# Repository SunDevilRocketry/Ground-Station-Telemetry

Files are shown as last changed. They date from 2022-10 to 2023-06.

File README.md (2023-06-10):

<h1>Ground Station Telemetry Unit</h1>

<p>Current PCB Revision: 1.0</p>
<p>PCB Part Number: A0005</p>

<p>The Ground Station Telemetry Unit adds wireless connectivity to the Raspberry-Pi 
based ground station computer. The unit is equipped with a socket for an XBee module, as well as a LoRa module.</p>

<p><b>Working Directory Structure:</b></p>

<p>
   doc: documentation
   
   src: source design files, e.g. schematic and PCB layout files

   lib: libraries for schematic symbols and footprints

   production: files needed for pcb fabrication, e.g. gerbers, profile, drill file

   sim: simulation models/files 

   cad: 3d models
  
   img: images of circuit/footprints for github display 
</p>

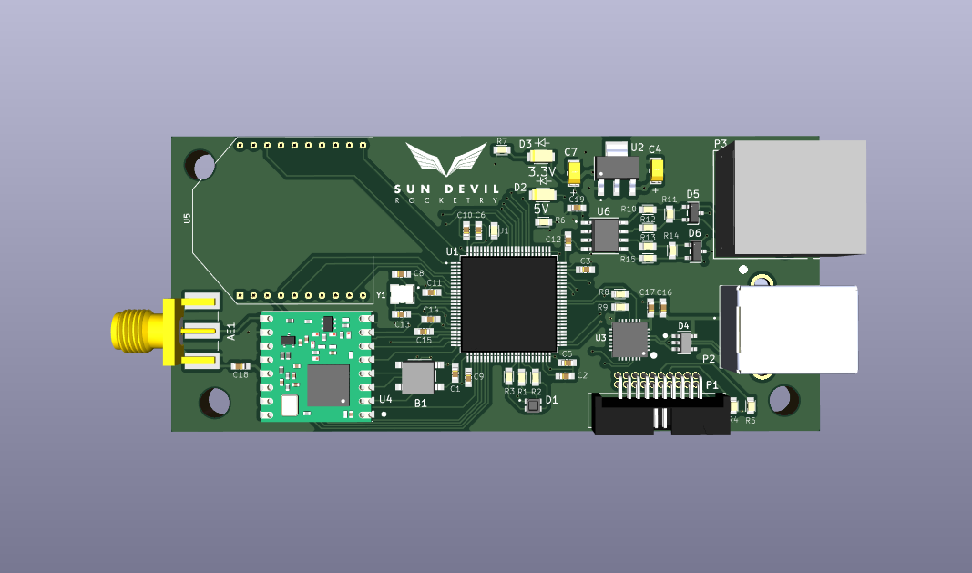
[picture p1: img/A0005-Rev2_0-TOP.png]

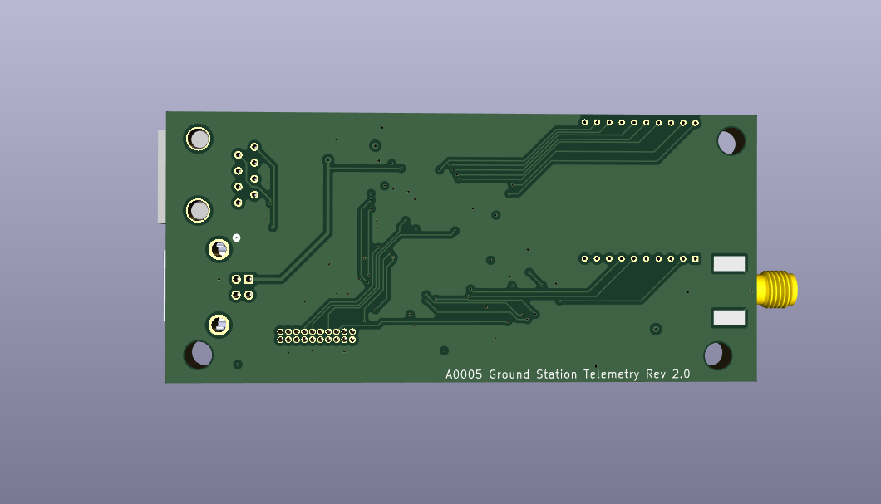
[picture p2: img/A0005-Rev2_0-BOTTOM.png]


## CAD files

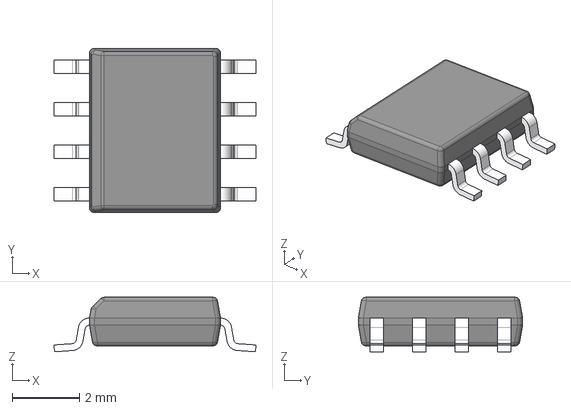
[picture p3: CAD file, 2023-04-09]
CAD/3Dfiles/sn65hcd71.step
6.02 x 4.90 x 1.63 mm
BODY-SO
LEAD-D0008A x 8

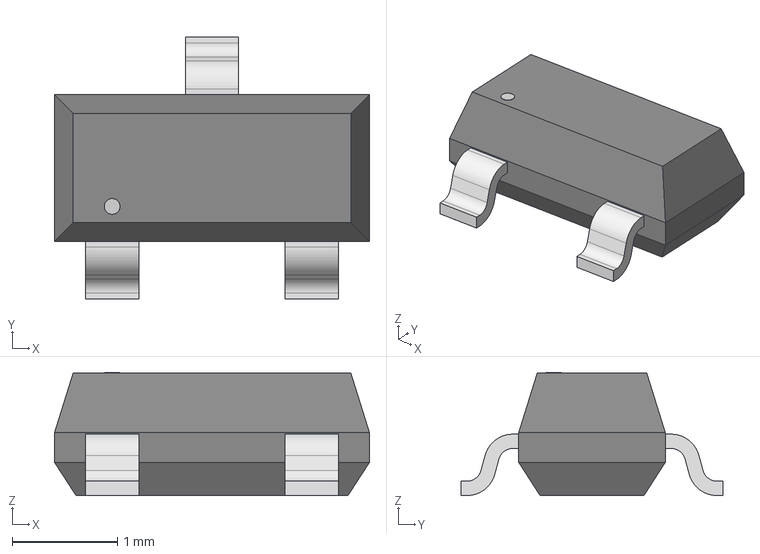
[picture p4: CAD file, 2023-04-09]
CAD/3Dfiles/CDSOT23-SM712.step
3.00 x 2.49 x 1.17 mm

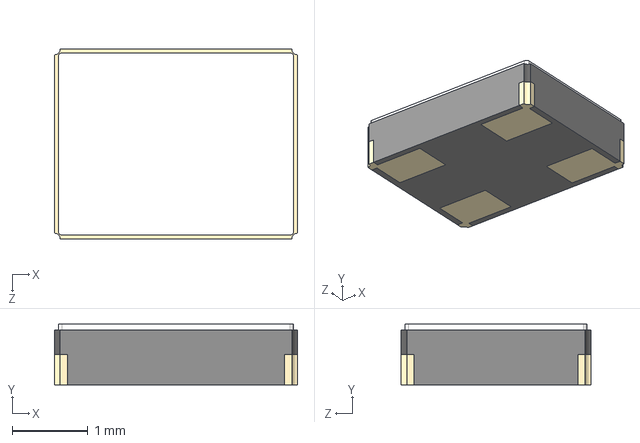
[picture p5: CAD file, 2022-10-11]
CAD/3Dfiles/ECS-240-18-33-JGN-TR.STEP
3.20 x 0.8 x 2.50 mm

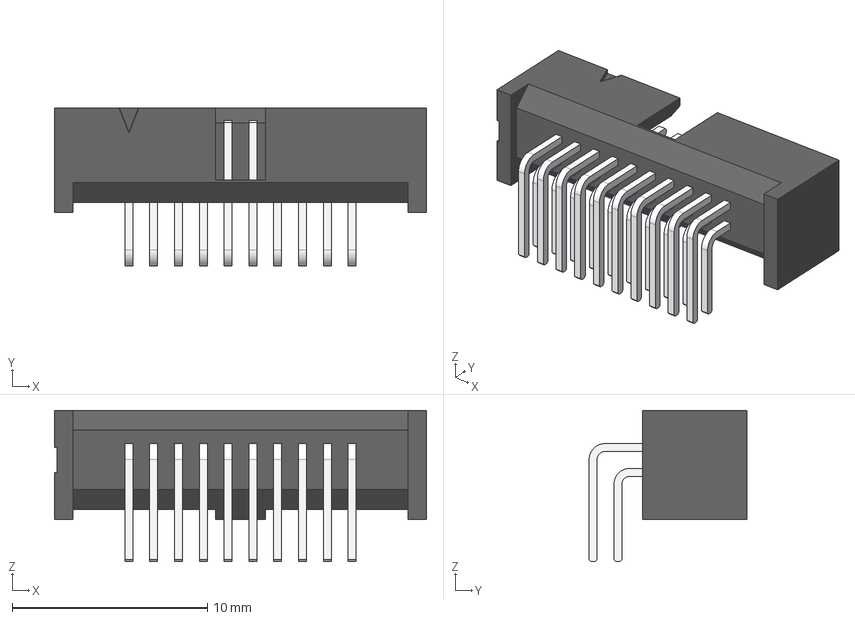
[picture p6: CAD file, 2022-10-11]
CAD/3Dfiles/3220-20-0200-00.stp
19.1 x 8.08 x 7.75 mm
_SHF-110-01-D_header
_SHF-First_Position_Indicator
_T-1S71-02-10-D-RA

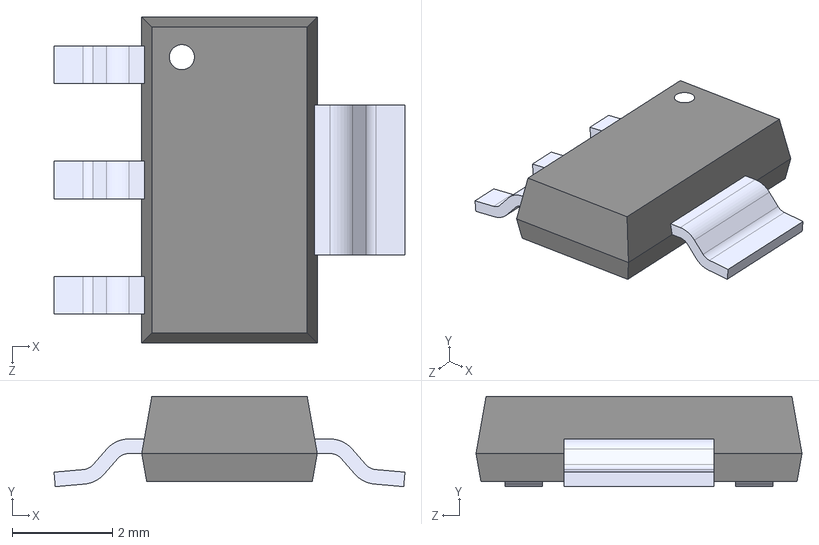
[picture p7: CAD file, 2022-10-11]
CAD/3Dfiles/LMS8117AMP-3.3NOPB.STEP
7.00 x 1.80 x 6.50 mm

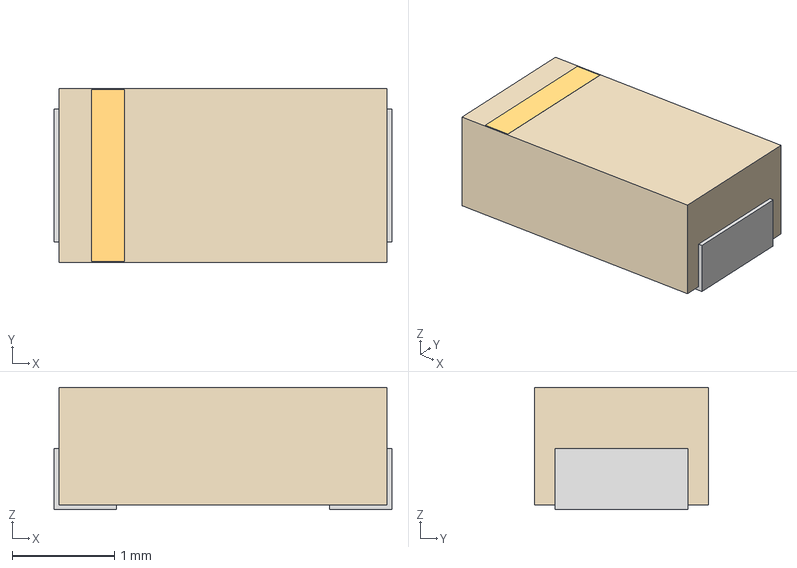
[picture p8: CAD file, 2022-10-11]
CAD/3Dfiles/SML-LX1206GC-TR.step
3.30 x 1.70 x 1.20 mm

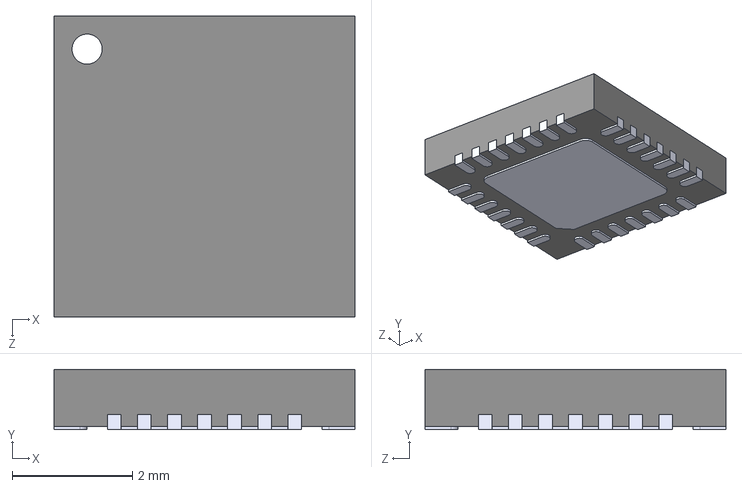
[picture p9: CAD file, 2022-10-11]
CAD/3Dfiles/CP2102-GMR_QFN28.step
5.00 x 1.00 x 5.00 mm

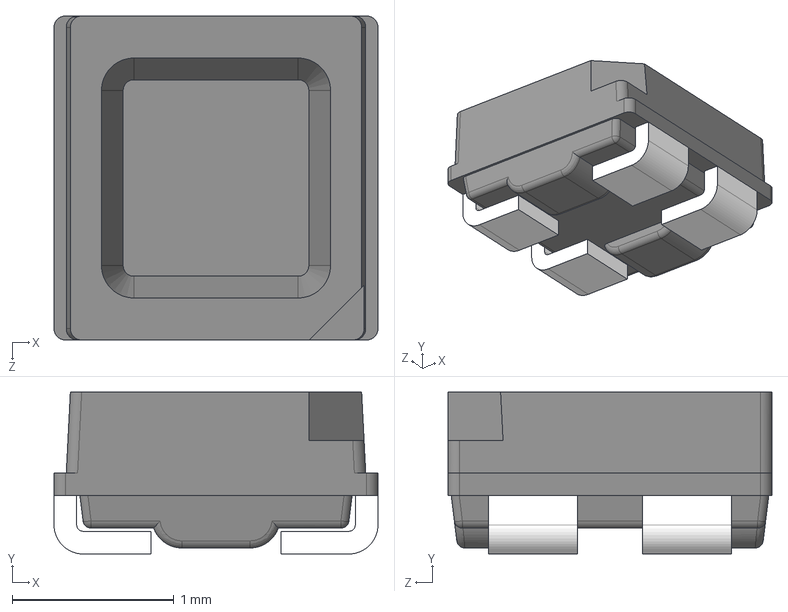
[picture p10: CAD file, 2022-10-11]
CAD/3Dfiles/CLMVC-FKA-CL1D1L71BB7C3C3.STEP
2.00 x 1 x 2.00 mm

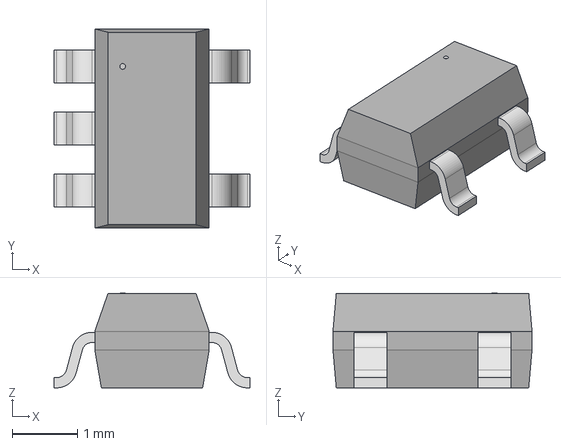
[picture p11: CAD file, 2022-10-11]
CAD/3Dfiles/SP0504BAHTG.step
3.00 x 3.05 x 1.45 mm

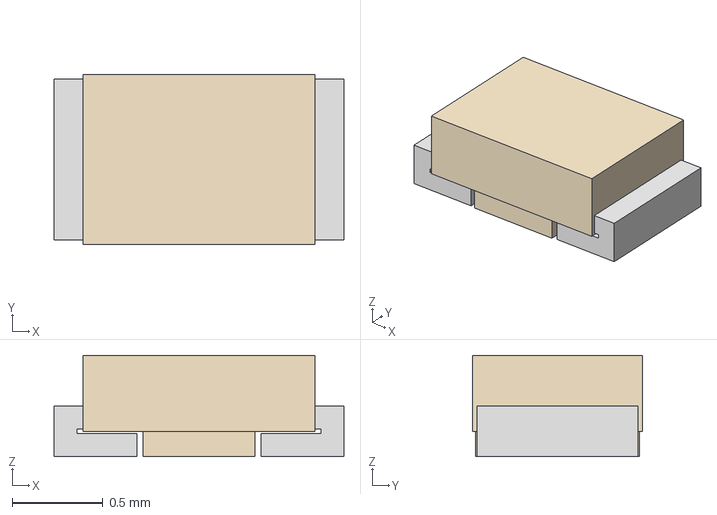
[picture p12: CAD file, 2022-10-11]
CAD/3Dfiles/RES_0603.step
1.60 x 0.94 x 0.559 mm

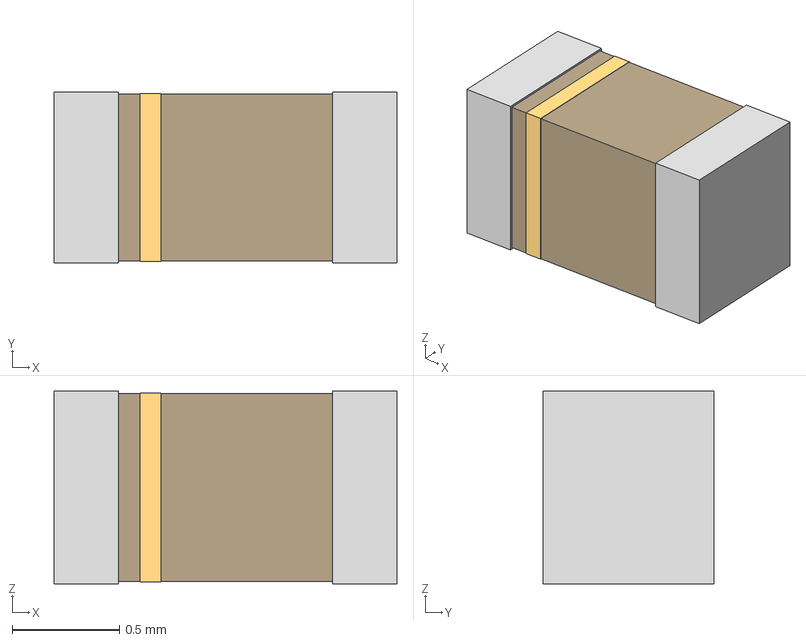
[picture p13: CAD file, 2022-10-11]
CAD/3Dfiles/CAP_0603.step
1.60 x 0.8 x 0.9 mm

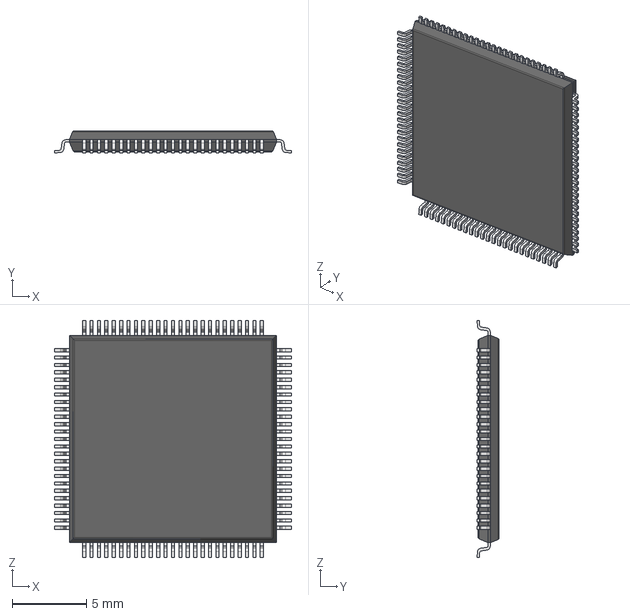
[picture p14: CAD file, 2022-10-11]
CAD/3Dfiles/stm32h750vbt6.stp
16.0 x 1.48 x 16.0 mm

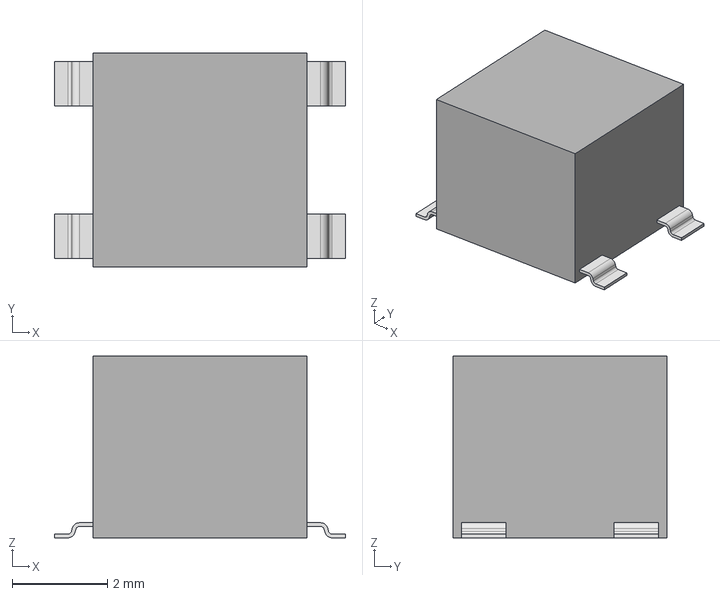
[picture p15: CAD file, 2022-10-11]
CAD/3Dfiles/SW_PTS647SM38SMTR2LFS_CNK.step
6.10 x 4.50 x 3.81 mm

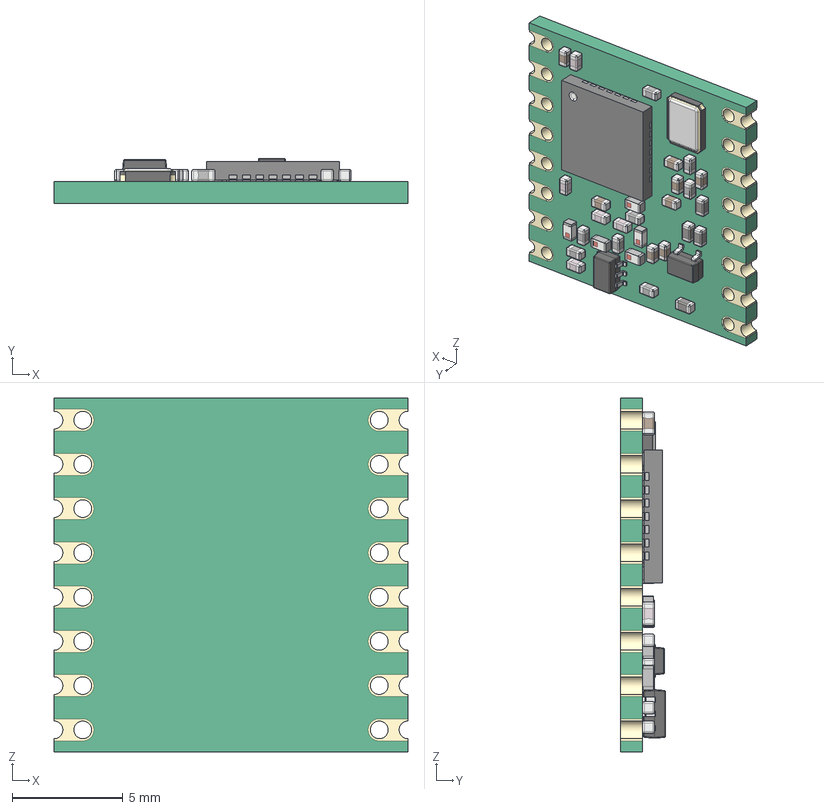
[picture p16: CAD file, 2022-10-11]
CAD/3Dfiles/RFM95.step
16.0 x 2.04 x 16.0 mm
QFN 28
SMD Crystal
CAP 0403 x 8
CAP Ceramic 0403 x 8
Res 0403 x 4
CAP ML 0403 x 5
SOT-323
Inductor SMD 0403 x 5
SOT-363

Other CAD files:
CAD/3Dfiles/T491A106K010AT.step
CAD/3Dfiles/142-0701-801.STEP
CAD/3Dfiles/SS-52300-001--3DModel-STEP-56544.STEP
CAD/3Dfiles/282837-2.step
CAD/3Dfiles/54602-908LFc.stp

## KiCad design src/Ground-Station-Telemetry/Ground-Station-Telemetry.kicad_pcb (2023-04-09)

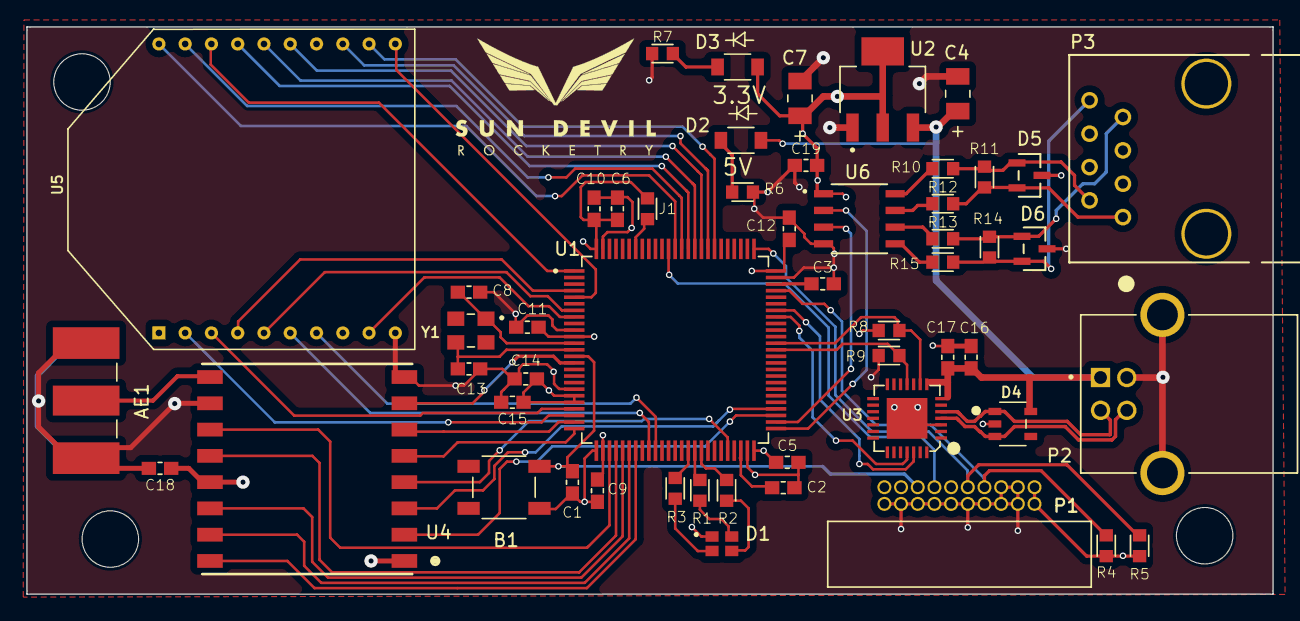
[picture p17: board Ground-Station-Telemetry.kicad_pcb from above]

Board: 4 copper layers, 94.9 x 43.2 mm, 57 parts (0 on the bottom side), 64 nets.

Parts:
AE1: 142-0701-851
B1: PTS647SM38SMTR2LFS
C1, C5, C9, C10, C11, C12, C14, C17, C18, C19: 0.1uF; CAP_0603
C2, C3: 2.2uF; CAP_0603
C4, C7: 10uF; T491A106K010AT
C6: 4.7uF; CAP_0603
C8, C13: 8pF; CAP_0603
C15, C16: 1uF; CAP_0603
D1: CLMVC-FKA-CL1D1L71BB7C3C3
D2, D3: SML-LX1206GC-TR
D4: SP0504BAHTG
D5, D6: SMBJ36CA-13-F; CDSOT23-SM712
H1, H2, H4: Mounting-Hole; MountingHole_4.3mm_M4_DIN965
J1: Jumper_NO; RES_0603
LOGO1: Logo
P1: 3220-20-0200-00
P2: USB; USB-TypeB
P3: 54602-908LF
R1: 68; RES_0603
R2: 82; RES_0603
R3: 280; RES_0603
R4, R5: 100k; RES_0603
R6, R7: 240; RES_0603
R8: 4.7k; RES_0603
R9: 10k; RES_0603
R10, R12, R13, R15: 10; RES_0603
R11, R14: 100; RES_0603
U1: STM32H750VBTx; STM32H750VBT6
U2: LMS8117AMP-3.3_NOPB; LMS8117AMP-3.3NOPB
U3: CP2102-GMR(QFN28); CP2012-GMR
U4: RFM95W-868S2; RFM95
U5: XB24CDMPIT-001; XBee
U6: SN65HVD71DR
Y1: ECS-240-18-33-JGN-TR

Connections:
3.3V: C5.1, C6.1, C7.1, C9.1, C10.1, C11.1, C12.1, C14.1, C15.1, C18.1, C19.1, D1.1, D3.2, J1.1 (A), P1.1, P1.2, R4.2, R5.2, R8.1, U1.11 (VDD), U1.20 (VREF+), U1.21 (VDDA), U1.27 (VDD), U1.50 (VDD), U1.75 (VDD), U1.100 (VDD), U2.2 (VOUT), U4.13 (3_3V), U5.1 (VCC), U6.1 (VCC)
5V: C4.1, C16.1, C17.1, D2.2, D4.5, P2.1 (VCC), U2.3 (VIN), U3.7 (REGIN), U3.8 (VBUS)
/Connectivity/D+: D4.3, P2.3 (D+), U3.4 (D+)
/Connectivity/D-: D4.1, P2.2 (D-), U3.5 (D-)
A: D5.1, P3.2, R10.2, R11.2
B: D5.2, P3.1, R11.1, R12.2
BOOT: J1.2 (B), U1.94 (BOOT0)
CAP1: C2.1, U1.48 (VCAP1)
CAP2: C3.1, U1.73 (VCAP2)
Earth: AE1.2 (Shield), B1.1, C1.2, C2.2, C3.2, C4.2, C5.2, C6.2, C7.2, C8.2, C9.2, C10.2, C11.2, C12.2, C13.2, C14.2, C15.2, C16.2, C17.2, C18.2, C19.2, D4.2, D5.3, D6.3, P1.3, P1.4, P1.5, P1.6, P1.8, P1.10, P1.12, P1.14, P1.16, P1.18, P1.20, P2.4 (GND), P2.S1 (SHIELD), P2.S2 (SHIELD), R6.1, R7.1, R9.1, U1.10 (VSS), U1.19 (VSSA), U1.26 (VSS), U1.49 (VSS), U1.74 (VSS), U1.99 (VSS), U2.1 (GND), U3.3 (GND), U3.29 (PAD), U4.1 (GND), U4.8 (GND@1), U4.10 (GND@2), U5.10 (GND), U6.4 (GND)
LORA_IO0: U1.30 (PA6), U4.14 (DIO0)
LORA_IO1: U1.31 (PA7), U4.15 (DIO1)
LORA_IO2: U1.32 (PC4), U4.16 (DIO2)
LORA_IO3: U1.28 (PA4), U4.11 (DIO3)
LORA_IO4: U1.29 (PA5), U4.12 (DIO4)
LORA_IO5: U1.15 (PC0), U4.7 (DIO5)
LORA_MISO: U1.53 (PB14), U4.2 (MISO)
LORA_MOSI: U1.54 (PB15), U4.3 (MOSI)
LORA_RST: U1.24 (PA2), U4.6 (RESET)
LORA_SCK: U1.46 (PB10), U4.4 (SCK)
LORA_SS: U1.25 (PA3), U4.5 (NSS)
NRST: B1.3, C1.1, P1.15, U1.14 (NRST)
unnamed: AE1.1 (A), U4.9 (ANT)
unnamed: D1.2, R1.2
unnamed: D1.3, R2.2
unnamed: D1.4, R3.2
unnamed: D2.1, R6.2
unnamed: D3.1, R7.2
unnamed: R10.1, U6.8 (A)
unnamed: R12.1, U6.7 (B)
unnamed: R15.1, U6.5 (Y)
unnamed: R13.1, U6.6 (Z)
OSC_IN: C8.1, U1.12 (PH0), Y1.1
OSC_OUT: C13.1, U1.13 (PH1), Y1.3
RS485_RX: U1.51 (PB12), U6.2 (R)
RS485_TX: U1.52 (PB13), U6.3 (D)
STATUS_B: R1.1, U1.41 (PE11)
STATUS_G: R2.1, U1.42 (PE12)
STATUS_R: R3.1, U1.40 (PE10)
SWCLK: P1.9, R5.1, U1.76 (PA14)
SWDIO: P1.7, R4.1, U1.72 (PA13)
SWO: P1.13, U1.89 (PB3)
USB_RX: U1.68 (PA9), U3.25 (RXD)
USB_TX: U1.69 (PA10), U3.26 (TXD)
XBEE_DIO0: U1.88 (PD7), U5.20 (DIO0)
XBEE_DIO1: U1.87 (PD6), U5.19 (DIO1)
XBEE_DIO5: U1.84 (PD3), U5.15 (DI05)
XBEE_DIO6: U1.85 (PD4), U5.16 (DIO6)
XBEE_DIO7: U1.82 (PD1), U5.12 (DI07)
XBEE_DIO8: U1.8 (PC14), U5.9 (DI8)
XBEE_MISO: U1.4 (PE5), U5.4 (MISO)
XBEE_MOSI: U1.5 (PE6), U5.11 (MOSI)
XBEE_PWM0: U1.34 (PB0), U5.6 (PWM0)
XBEE_PWM1: U1.35 (PB1), U5.7 (PWM1)
XBEE_RX: U1.22 (PA0), U5.3 (RX)
XBEE_SCK: U1.1 (PE2), U5.18 (SCK)
XBEE_SS: U1.86 (PD5), U5.17 (SPI_SS)
XBEE_TX: U1.23 (PA1), U5.2 (TX)
Y: D6.2, P3.8, R14.1, R15.2
Z: D6.1, P3.7, R13.2, R14.2
~USB_RST: R8.2, U1.64 (PC7), U3.9 (~RST)
~USB_SUSPEND: R9.2, U1.63 (PC6), U3.11 (~SUSPEND)
~XBEE_RST: U1.7 (PC13), U5.5 (~RESET)
~XBEE_SLEEP: U1.83 (PD2), U5.13 (~SLEEP)

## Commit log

2022-10-11 added component symbols to library
    [Ground-Station-Telemetry.kicad_pcb, Ground-Station-Telemetry.kicad_sch]
2022-10-11 populated footprint library
    [142-0701-801.STEP, 3220-20-0200-00.stp, CAP_0603.step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]
2022-10-11 created rev1 schematic
    [Connectivity.kicad_sch, Ground-Station-Telemetry.kicad_sch]
2022-10-11 routed rev1
    [Connectivity.kicad_sch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]
2023-04-09 added rs485 components to rev 2 lib files
    [282837-2.step, 54602-908LFc.stp, CDSOT23-SM712.step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]
2023-04-09 added RS485 transceiver to schematic
    [Connectivity.kicad_sch, Ground-Station-Telemetry.kicad_sch]
2023-04-09 finished initial rev 2 routing
    [Connectivity.kicad_sch, Ground-Station-Telemetry.kicad_pcb, Ground-Station-Telemetry.kicad_sch]
2023-04-09 resolved DRC errors
    [Ground-Station-Telemetry.kicad_pcb]
2023-04-09 generated production files
    [Ground-Station-Telemetry-B_Cu.gbr, Ground-Station-Telemetry-B_Mask.gbr, Ground-Station-Telemetry-B_Paste.gbr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]
2023-06-10 added PCB images to README
    [Connectivity.kicad_sch]

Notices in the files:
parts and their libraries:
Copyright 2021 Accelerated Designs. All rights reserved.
